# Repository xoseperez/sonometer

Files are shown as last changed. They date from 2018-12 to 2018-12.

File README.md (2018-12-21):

# Sonometer

This is a simple sonometer based on Arduino. It uses an electret mic with analog output to read the environment noise.
A potentiometer to set the sensitivity and a 24 bits LED ring as a visual display of the noise level.
This sonometer code and case is part of the [Slices project](https://github.com/xoseperez/slices.git).

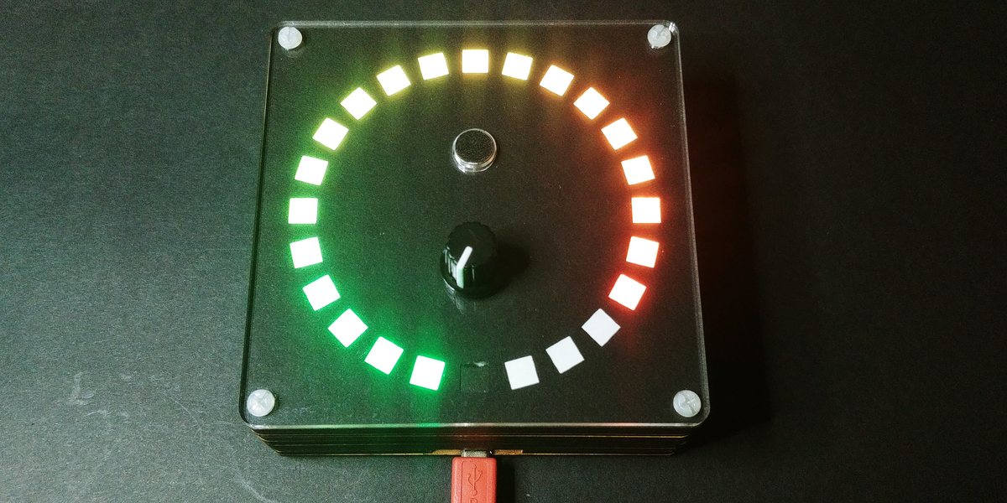
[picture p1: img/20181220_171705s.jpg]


## Hardware

### The box

The hardware has been designed using [OpenSCad](http://www.openscad.org)
and it's inspired by the [PiBow](https://www.raspberrypi.org/blog/pibow/)
cases for Raspberry Pi. A series of layers forming a sandwich. From top to bottom
the layers are (this is true for beta version):

* front, a transparent acrylic layer cut with a laser cutter
* stencil, a thin black cardboard with the individual LEDs cut out with a laser
* diffusor, a thin white paper sheet
* grid, a thin 2.5mm wood layer to isolate each pixel
* LED matrix, a 24 bits LED ring w/ WS2812B pixels
* LED matrix support in MDF
* MDF hollow layers to allow room for the electronics
* back, a clear acrylic layer or MDF again

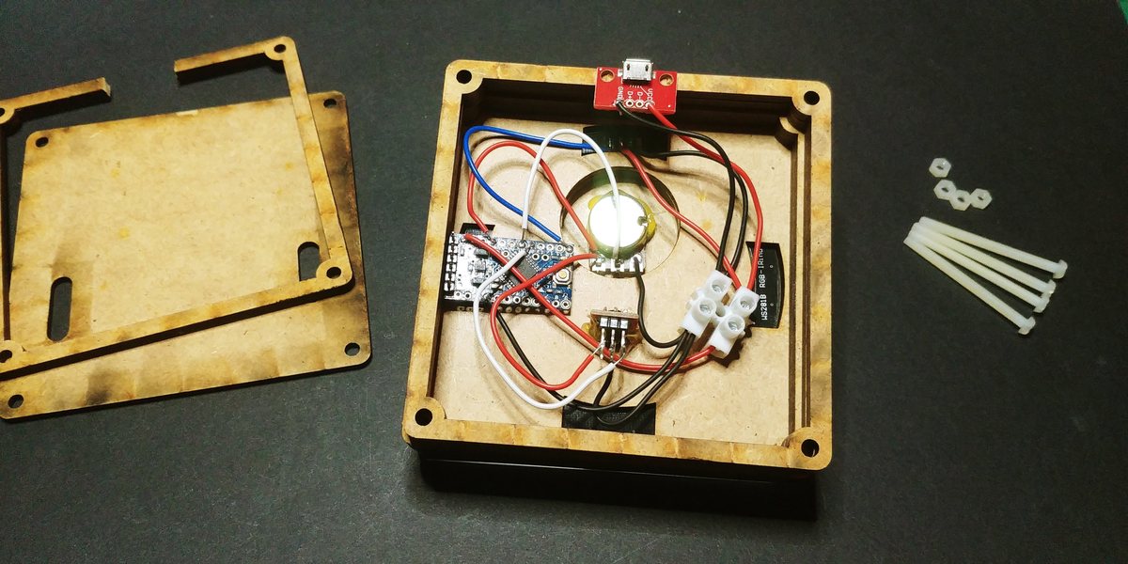
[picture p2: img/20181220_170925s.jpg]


### The electronics

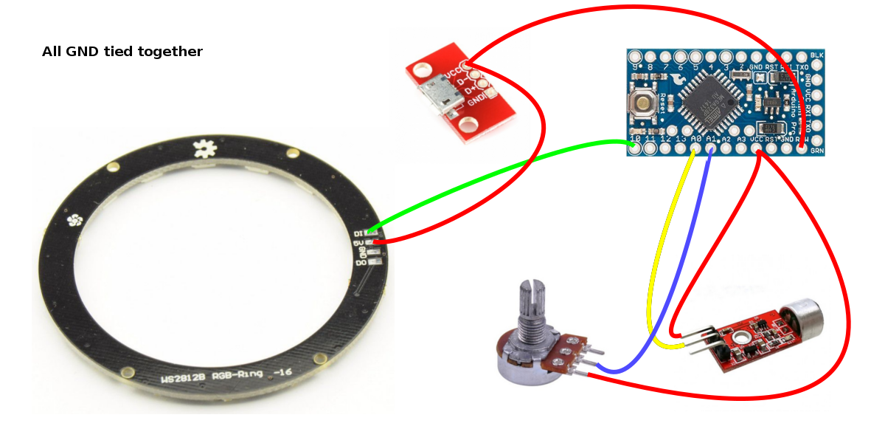
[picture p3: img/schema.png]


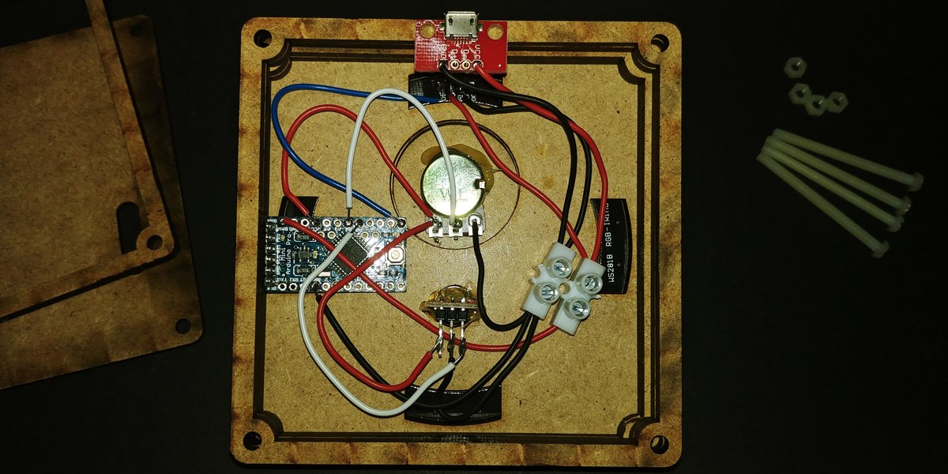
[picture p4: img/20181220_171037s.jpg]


## Firmware

The firmware is meant to be burn to an Arduino Minio Pro but is is easily ported to any other similar plarform.

The project is ready to be build using [PlatformIO](http://www.platformio.org).
Please refer to their web page for instructions on how to install the builder.
Once installed:

```bash
> cd code
> platformio run
> platformio run --target upload
```

Library dependencies are automatically managed via PlatformIO Library Manager.

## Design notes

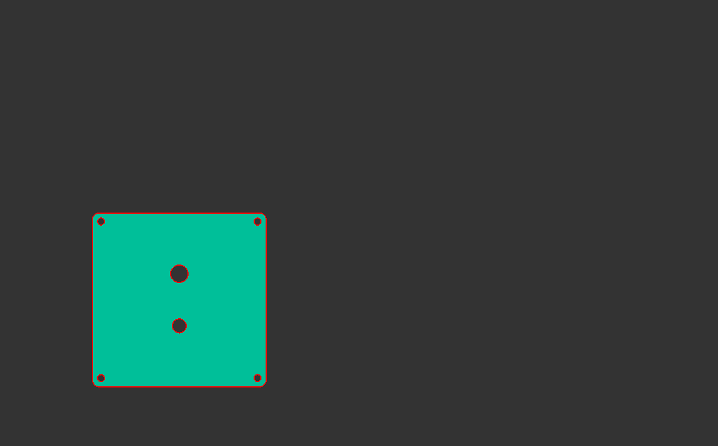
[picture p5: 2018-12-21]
model/sonometer-paper-white.png

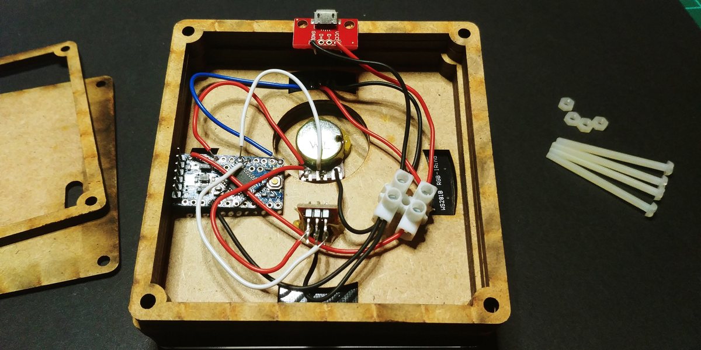
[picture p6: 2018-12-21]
img/20181220_170931s.jpg

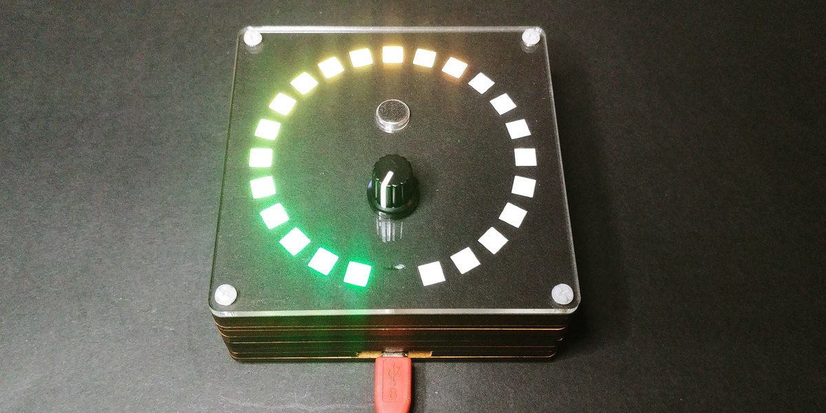
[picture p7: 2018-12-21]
img/20181220_171722s.jpg

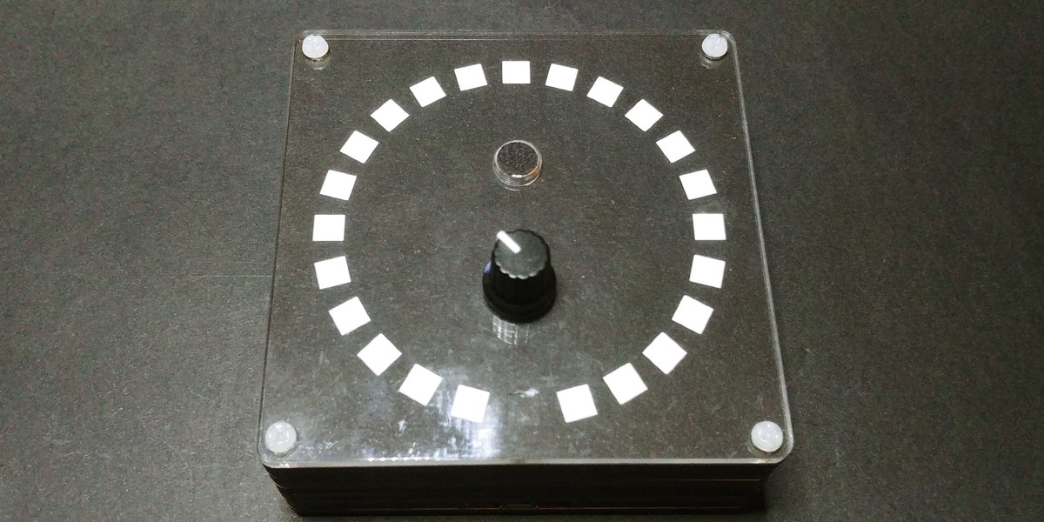
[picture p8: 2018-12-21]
img/20181220_171629s.jpg

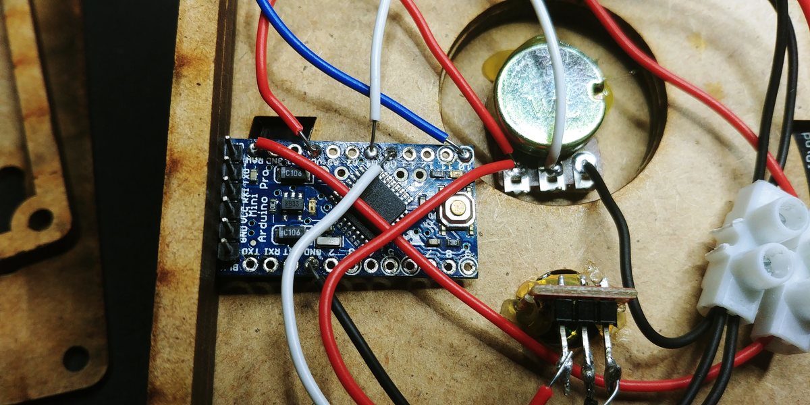
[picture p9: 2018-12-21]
img/20181220_171043s.jpg

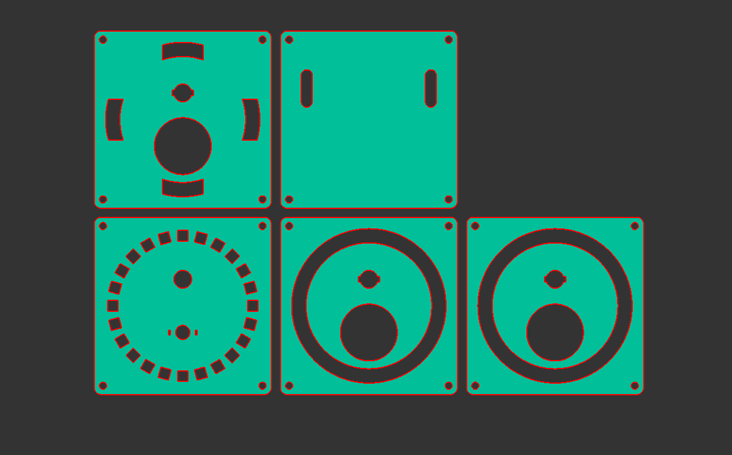
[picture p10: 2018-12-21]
model/sonometer-wood-2_5mm.png

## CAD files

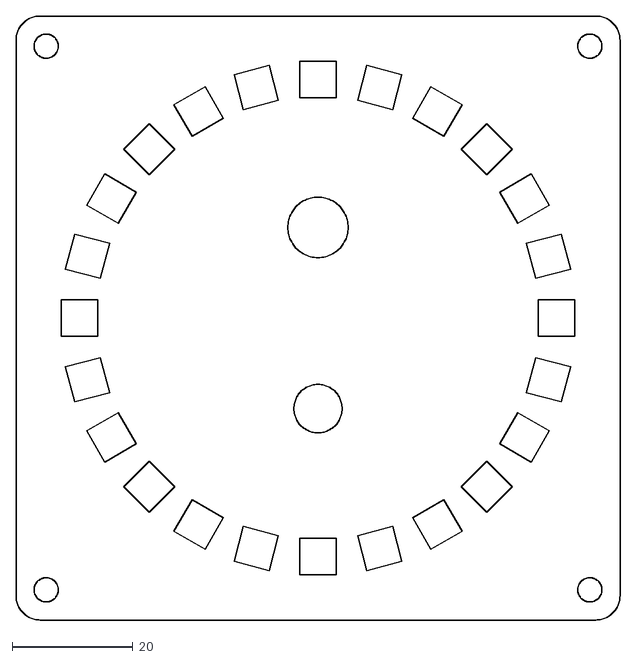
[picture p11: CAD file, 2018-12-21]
model/sonometer-paper-black.dxf
100.0 x 100.0

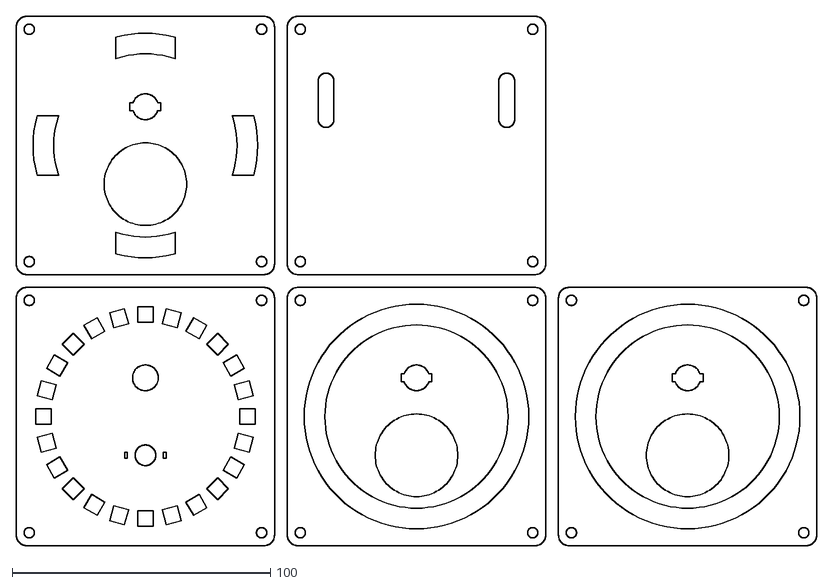
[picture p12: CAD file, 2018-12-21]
model/sonometer-wood-2_5mm.dxf
310.0 x 205.0

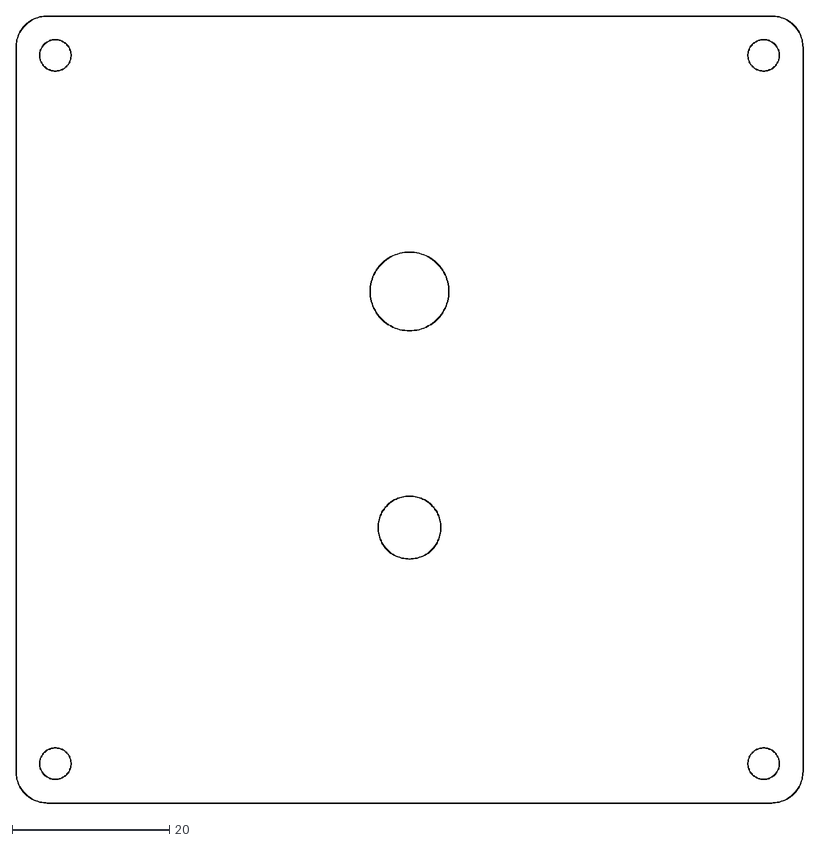
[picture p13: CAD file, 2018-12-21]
model/sonometer-paper-white.dxf
100.0 x 100.0

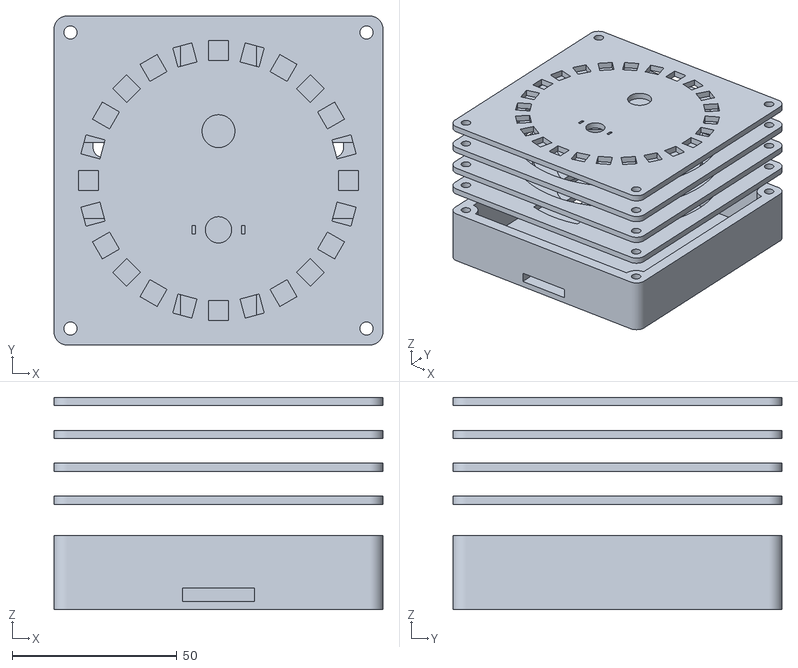
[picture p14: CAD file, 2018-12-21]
model/sonometer-wood.stl
100.0 x 100.0 x 64.5

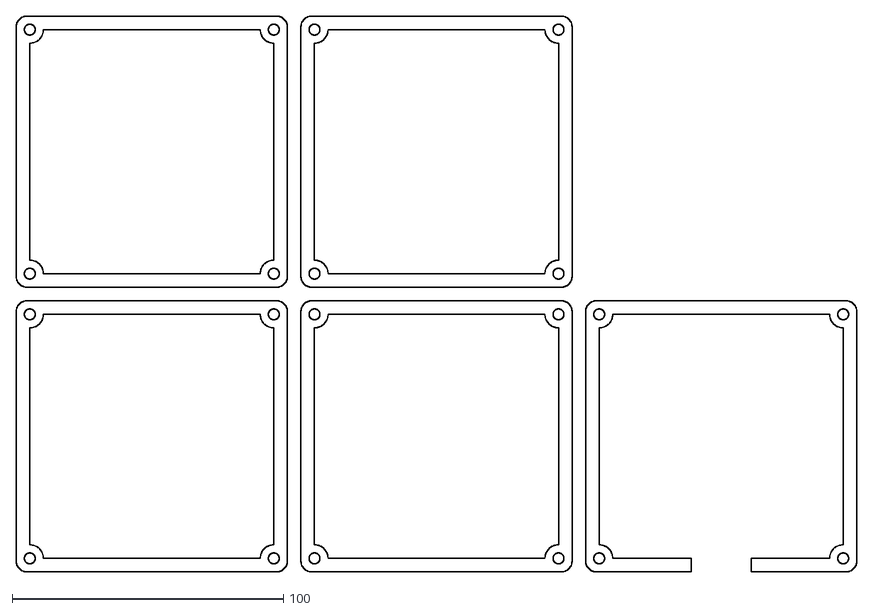
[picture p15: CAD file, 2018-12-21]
model/sonometer-wood-4mm.dxf
310.0 x 205.0

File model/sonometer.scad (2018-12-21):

//-----------------------------------
// Configuration
//-----------------------------------

// Precission
$fn=100;

// Model size
model_size=100;

// Circle types (count, inner, outer)
circle = [
    [60, 71.5, 79.5],
    [24, 35.5, 43.5]
];

// Size of an individual LED
led_side=6;

// Shift LED circle 
led_shift = 0;

// Holes radius (half of metric: M3, M4...)
hole_size=2; // M4

// Hole distance to edge
hole_distance=5;

// Minkowski radius
chamfer_size=4;

// Gap between pieces
gap = 5;

// Gap between 3d pieces
gap3d = 3;

//-----------------------------------
// DO NOT TOUCH BELOW THIS LINE
//-----------------------------------

//-----------------------------------
// Components
//-----------------------------------

module base() {
    
    difference() {
        
        // Shape
        minkowski() {
            square(model_size-2*chamfer_size, true);
            circle(chamfer_size);
        }

        // Holes
        for(i=[0:3]) {
            rotate(90*i) {
                translate([model_size/2-hole_distance,model_size/2-hole_distance,0]) {
                    circle(hole_size, center=true);
                }
            }
        }

    }
}

module led_circle_negative(type, led_side, shift) {

    count = circle[type][0];
    inner = circle[type][1];
    outer = circle[type][2];
    radius = (inner + outer)/2;

    for (i=[0:count]) {
        rotate(360 * (i+shift) / count)
            translate([0, radius])
                square([led_side, led_side], true);
    }

}
    
module potentiometer_negative(mark=0, body=0) {
    if (body==0) circle(4);
    if (mark) {
        translate([7.5,0,0])
            square([1,2.5], true);
        translate([-7.5,0,0])
            square([1,2.5], true);
    }
    if (body==1) circle(16);
}

module mic_negative(body=0) {
    union() {
        circle(5);
        if (body==1) square([12,3], true);
    }
}

module wall_hole() {
    rotate(180)
        minkowski() {
            square([0.1,15]);
            circle(3);
        }
}

module socket_hole() {
    circle(11.4/2);
}

//-----------------------------------
// Layers
//-----------------------------------

module layer_front() {
    difference() {
        base();
        translate([0, -15]) potentiometer_negative(0);
        translate([0, 15]) mic_negative(0);
    }
}

module layer_grid(mark) {
    difference() {
        base();
        led_circle_negative(1, led_side, led_shift);
        translate([0,-15]) potentiometer_negative(mark,0);
        translate([0,15]) mic_negative(0);
    }
}

module layer_cast(hole) {
    difference() {
        base();
        difference() {
            circle(circle[1][2], center=true);
            circle(circle[1][1], center=true);
        }
        translate([0,-15]) potentiometer_negative(1,hole);
        translate([0,15]) mic_negative(1);
    }
}

module layer_support() {

    difference() {
        
        base();
        
        inner = circle[1][1];
        outer = circle[1][2];
        
        difference() {
            circle(outer, center=true);
            circle(inner, center=true);
            for (i=[0:3]) rotate(90*i) {
                translate([model_size/2, model_size/2 ]) {
                    square(model_size/1.3, true);
                }
            }
        }

        translate([0,-15]) potentiometer_negative(1,1);
        translate([0,15]) mic_negative(1);

    }

}

module layer_hollow() {
    difference() {
        base();
        difference() {
            square(model_size-2*hole_distance,true);
            for(i=[0:3]) 
                rotate(90*i)
                    translate([
                        model_size/2-hole_distance,
                        model_size/2-hole_distance
                    ])
                        circle(5);
        }
    }
}

module layer_hollow_cutout() {
    difference() {
        layer_hollow();
        translate([0,-model_size/2,0]) square([22,10], true);
    }
}

module layer_back_wall() {
    difference() {
        base();
        translate([-model_size/2 + 15, model_size/2 - 25,0]) wall_hole();
        translate([model_size/2 - 15, model_size/2 - 25,0]) wall_hole();
    }
}

//-----------------------------------
// Layers to render
//-----------------------------------

// acrylic-transparent-3mm ----------
//layer_front(); 

// paper-black ----------------------
layer_grid(0);

// paper-white ----------------------
//layer_front(); 

// wood-4mm -------------------------
/*
for(x=[0:1]) for(y=[0:1]) {
    translate([
        (model_size + gap) * x,
        (model_size + gap) * y
    ]) layer_hollow();
}
translate([
    (model_size + gap) * 2,
    (model_size + gap) * 0
]) layer_hollow_cutout();
*/

// wood-2.5mm -----------------------
/*
translate([
    (model_size + gap) * 0,
    (model_size + gap) * 0
]) layer_grid(1);
translate([
    (model_size + gap) * 1,
    (model_size + gap) * 0
]) layer_cast(1);
translate([
    (model_size + gap) * 0,
    (model_size + gap) * 1
]) layer_support();
translate([
    (model_size + gap) * 1,
    (model_size + gap) * 1
]) layer_back_wall();
translate([
    (model_size + gap) * 2,
    (model_size + gap) * 0
]) layer_cast(1);
*/

// 3D ------------------------------
/*
translate([0,0, 0.0]) linear_extrude(2.5) layer_back_wall(); 
translate([0,0, 2.5]) linear_extrude(  4) layer_hollow_cutout(); 
translate([0,0, 6.5]) linear_extrude( 16) layer_hollow(); 
translate([0,0,32.0]) linear_extrude(2.5) layer_support();
translate([0,0,42.0]) linear_extrude(2.5) layer_cast(1);
translate([0,0,52.0]) linear_extrude(2.5) layer_cast(1);
translate([0,0,62.0]) linear_extrude(2.5) layer_grid(1);
*/

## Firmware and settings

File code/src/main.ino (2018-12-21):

/*

Sonometer

Copyright (C) 2017 Xose Pérez <xose dot perez at gmail dot com>

Requires FastLED library (https://github.com/FastLED/FastLED)

---------------------------------------------------------------------

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
*/

#define SERIAL_BAUDRATE         115200

#define POTENTIOMETER_PIN       A1

#define LED_PIN                 10
#define LED_COUNT               24

#define MICROPHONE_PIN          A0
#define ADC_BITS                10
#define ADC_COUNTS              (1 << ADC_BITS)

#define NOISE_READING_WINDOW    20
#define NOISE_BUFFER_SIZE       20
#define NOISE_READING_DELAY     100
#define NOISE_MAX               1024

// -----------------------------------------------------------------------------

#include "FastLED.h"

// -----------------------------------------------------------------------------

CRGB leds[LED_COUNT];
unsigned int noise_buffer[NOISE_BUFFER_SIZE] = {0};
unsigned int noise_buffer_pointer = 0;
unsigned int noise_buffer_sum = 0;

// -----------------------------------------------------------------------------

CRGB getColor(unsigned int percent) {
    unsigned char red = map(percent, 0, 100, 0, 255);
    unsigned char green = map(percent, 0, 100, 255, 0);
    return CRGB(red, green, 0);
}

void showValue(unsigned int percent) {
    unsigned int num = LED_COUNT * percent / 100;
    for (unsigned int i=0; i<num; i++) {
        leds[i] = getColor(i * 100 / LED_COUNT);
    }
    for (unsigned int i=num; i<LED_COUNT; i++) {
        leds[i] = 0;
    }
    FastLED.show();
}

void noiseLoop() {

    static unsigned long last_reading = 0;

    unsigned int sample;
    unsigned int min = ADC_COUNTS;
    unsigned int max = 0;

    // Check MIC every NOISE_READING_DELAY
    if (millis() - last_reading < NOISE_READING_DELAY) return;
    last_reading = millis();

    // Get potentiomenter
    unsigned int max_noise = map(analogRead(POTENTIOMETER_PIN), 0, ADC_COUNTS, 0, NOISE_MAX);
    if (max_noise == 0) {
        FastLED.clear();
        FastLED.show();
        return;
    }

    while (millis() - last_reading < NOISE_READING_WINDOW) {
        sample = analogRead(MICROPHONE_PIN);
        if (sample < min) min = sample;
        if (sample > max) max = sample;
    }

    unsigned int peak = map(max - min, 0, ADC_COUNTS, 0, 100);

    noise_buffer_sum = noise_buffer_sum + peak - noise_buffer[noise_buffer_pointer];
    noise_buffer[noise_buffer_pointer] = peak;
    noise_buffer_pointer = (noise_buffer_pointer + 1) % NOISE_BUFFER_SIZE;

    showValue(constrain(map(noise_buffer_sum, 0, max_noise, 0, 100), 0, 100));

}

void setup() {
    Serial.begin(SERIAL_BAUDRATE);
    FastLED.addLeds<NEOPIXEL, LED_PIN>(leds, LED_COUNT);
    pinMode(MICROPHONE_PIN, INPUT);
    pinMode(POTENTIOMETER_PIN, INPUT);
}

void loop() {
    noiseLoop();
}

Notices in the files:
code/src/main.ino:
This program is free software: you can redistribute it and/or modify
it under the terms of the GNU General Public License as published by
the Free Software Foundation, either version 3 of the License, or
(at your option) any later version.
